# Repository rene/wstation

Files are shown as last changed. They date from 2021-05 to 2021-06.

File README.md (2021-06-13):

WStation Logo

*WStation* is a project that was born from my quarantine. I use to have one of those cheap Chinese thermometers. Unfortunately, it fell down to the floor, ending up with a broken LCD and a useless 433.92MHz sensor (since I didn't have any other device capable of decoding the signals). As you can imagine, perfect setup for a ESP32 project!

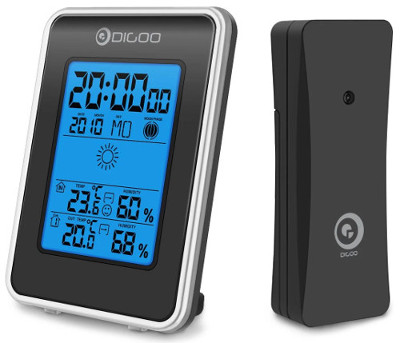
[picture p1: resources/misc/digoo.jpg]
Chinese Digoo Thermometer


*Original Device (Chinese Digoo thermometer)*

Since I had some free time due to the covid's quarantine, I've decided to start this project completely from scratch and release everything under BSD-3-Clause and CC licenses. Even the original mockup for the GUI can be found here.

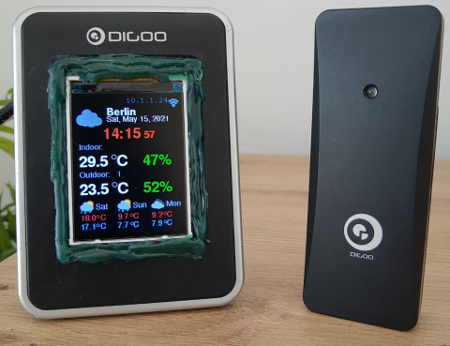
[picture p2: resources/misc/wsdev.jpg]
WStation device


*WStation device*

The prototype was made with a ESP32 DEVKIT V1 compatible device using the case of the broken Digoo thermometer (for sure there is room for visual improvements, specially on the hot glue the I've used to fill the holes on the borders, but in general the final result is not that bad). The radio receiver module have fit inside the case. ESP32 and DHT modules were assembled outside, on the back.

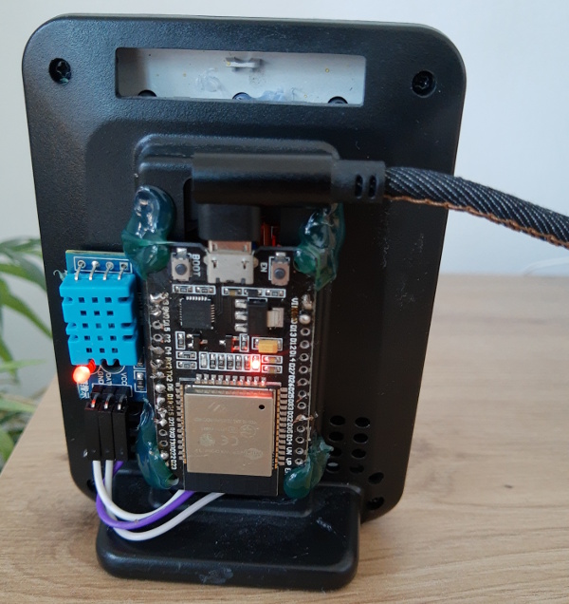
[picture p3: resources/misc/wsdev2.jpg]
WStation device - back


*ESP32 and DHT modules assembled on the back of the case*

WStation has the following features:

* WiFi connectivity
* NTP Client
* Timezone and Daylight Saving Time support
* Shows Indoor Temperature/Humidity
* Shows Outdoor (from external sensors) Temperature/Humidity (supports up to 3 sensors)
* Shows weekly forecast (next 3 days)
* Support to [OpenWeather](https://openweathermap.org/) API
* Support to DHT modules
* Support to HTU2x sensors
* Support to DS1307 RTC modules (optional)
* Support to 433.92MHz NC-7345 compatible sensors (optional)
* Web interface for device configuration (with user authentication)
* Reset setting to factory from button "press and hold"
* OTA firmware update (from Web interface)
* LCD brightness level control

## Hardware

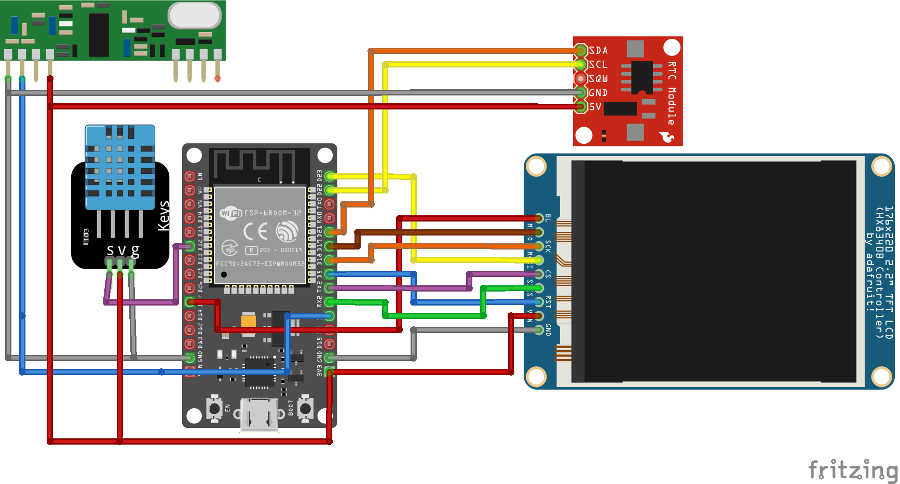
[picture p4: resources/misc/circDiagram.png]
WStation Circuit Diagram


*WStation circuit diagram*

The whole circuit can be built using a few modules:

| Module | Description |
| --- | --- |
| EPS32 module | ESP32 DEVKIT V1 compatible device |
| 240x320, 2.2" TFT LCD | SPI TFT LCD Serial Port Module Display ILI9341 5v/3.3v compatible screen |
| DHT module| DHT Sensor to measure Temperature and Humidity |
| DS1307 RTC module | Real Time Clock module (optional, date/time can be synchronized through NTP client) |
| 433.92MHz RF Receiver module | 433.92MHz RF Receiver (with ASK/OOK modulation support) |

DHT module can also be replaced by a high precision HTU2x Temperature/Humidity sensor module (connected through I2C):

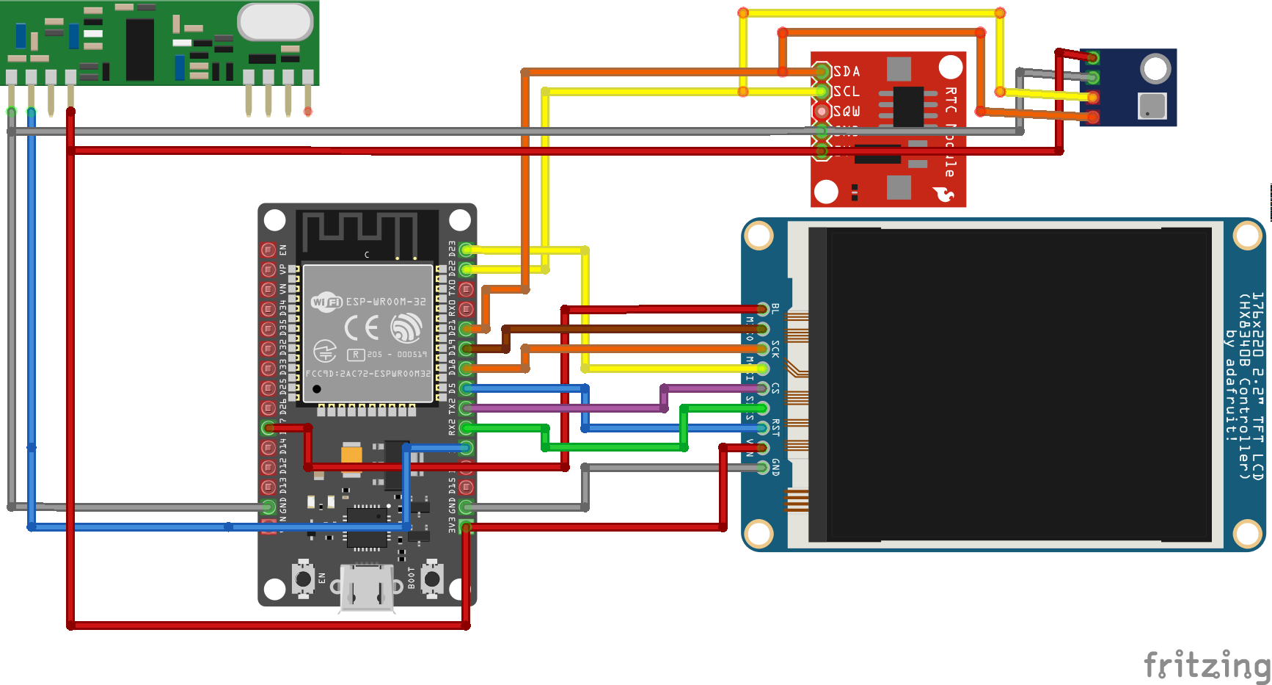
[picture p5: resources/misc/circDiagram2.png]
WStation Circuit Diagram with HTU2x sensor


### Pinout connection

| Function | Pin number |
| --- | --- |
| TFT module DC pin | 16 |
| TFT module CS pin| 17 |
| TFT module LED pin | 27 |
| TFT module SCK pin | 18 |
| TFT module MISO pin | 19 |
| TFT module MOSI pin | 23 |
| TFT module RST pin | 5 |
| DHT Data pin | 32 |
| Radio sensor | 4 |
| RTC SDA pin | 21 |
| RTC SCL pin | 22 |
| HTU2x SDA pin | 21 |
| HTU2x SCL pin | 22 |

## Firmware

### Setup the environment

To build the firmware, first make sure you have the Arduino/ESP32 environment installed as described at: [https://github.com/esp8266/Arduino](https://github.com/esp8266/Arduino) and [https://github.com/espressif/arduino-esp32](https://github.com/espressif/arduino-esp32). The firmware is built using *make* with the nice [makeEspArduino](https://github.com/plerup/makeEspArduino) makefile.

First, clone *WStation* repository:

```sh
git clone http://github.com/rene/wstation
cd wstation
```

Build and flash the file system:

```sh
$ cd src
$ make flash_fs
```

Build and flash the firmware:

```sh
$ make
$ make flash
```

Some environment variables can be customized according to user's setup:

| Variable | Description |
| --- | --- |
| UPLOAD_PORT | ESP module serial device, e.g. /dev/ttyUSB0 |
| UPLOAD_SPEED | Serial baud rate, e.g. 921600 |
| DEBUG_LEVEL | Verbose level for debug messages |
| RTC_DS1307 | Set to *true* if a RTC DS1307 module is installed |
| DHT_SENSOR | Set to *true* if a DHT module is installed |
| HTU2X_SENSOR | Set to *true* if a HTU2x modle is installed |
| ESP_LIBS | Path to Arduino/ESP libraries (if non default path is used) |
| ESP_ROOT | Root folder of Arduino/ESP environment (if non default path is used)  |

Once the device is flashed, future updates can be done through Web Interface. Just select and upload the *main.bin* file under *build* folder.

## Device setup

### Getting a OpenWeather API Key

*WStation* uses the [OpenWeather](https://openweathermap.org/) API to fetch updated weather forecasts. In order to use the API, you should subscribe to OpenWeather (free plan allows 60 requests per minute, which is completely fine for one *WStation* device) and get an API key. To get the key, please, follow the [Instructions](https://openweathermap.org/appid) at [OpenWeather](https://openweathermap.org/) website. After subscribe, you can generate and/or see your keys at the user's area:

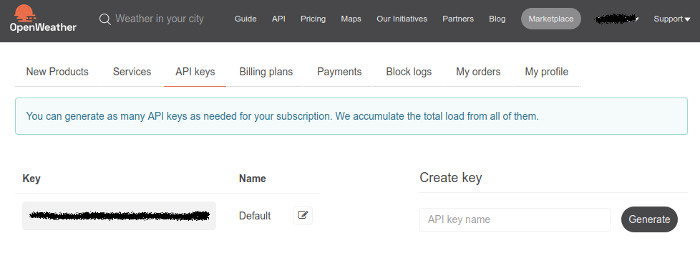
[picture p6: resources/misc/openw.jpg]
OpenWeather user interface


You will need to configure your API Key and city name (in OpenWeather's format, e.g. *Berlin,DE*) on *WStation* to start to get weather forecasts.

### Powering on the device

When you power on your *WStation* device for the first time, the device will act as an Access Point, creating the WiFi Network *WStation*. Connect to this network using the parameters shown on the screen:

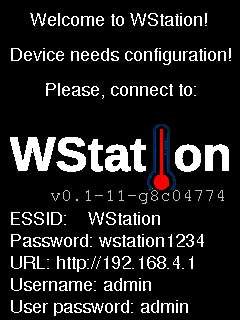
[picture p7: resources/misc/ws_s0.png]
WStation first screen


| Setting | Default value |
| --- | --- |
| WiFi SSID | *WStation* |
| WiFi Password | *wstation1234* |
| Username | *admin* |
| Password | *admin* |

Access device web interface to configure your API Key, City, WiFi network, etc. When the setup is done, click on the button *Save configuration*. That's it! Your *WStation* device is ready to work!

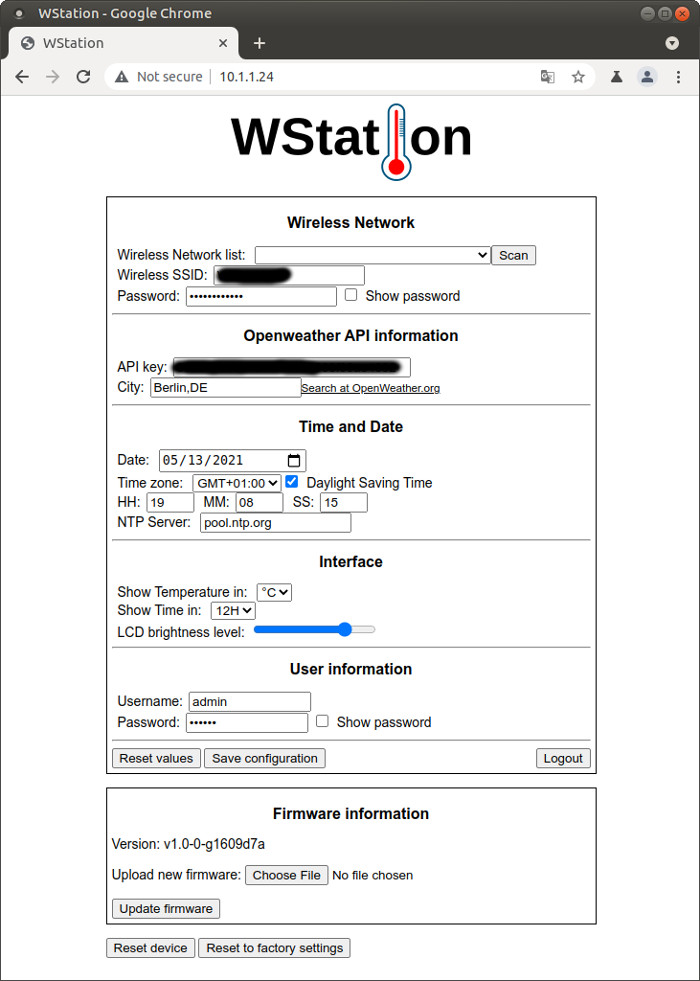
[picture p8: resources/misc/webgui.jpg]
WStation Web Interface


### Resseting to factory settings

Any *WStation* device can be redefined to factory settings by pressing and holding the *BOOT* button for 6 seconds or through the web interface.

### Screenshots of WStation interface

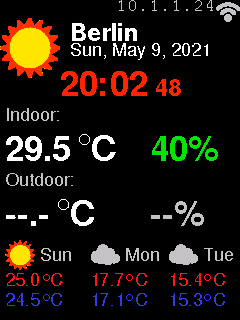
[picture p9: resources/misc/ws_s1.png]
WStation screenshot 1
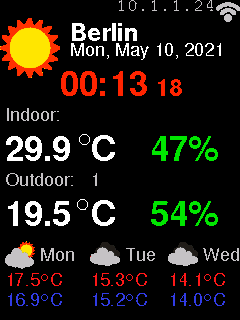
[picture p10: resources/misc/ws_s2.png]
WStation screenshot 2
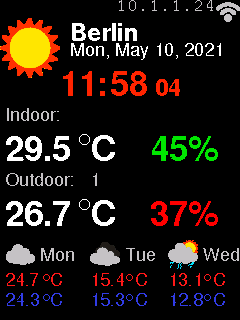
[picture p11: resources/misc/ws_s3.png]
WStation screenshot 3
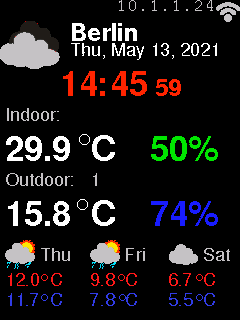
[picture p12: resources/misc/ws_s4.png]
WStation screenshot 4
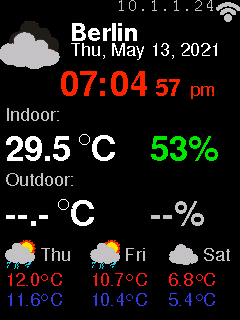
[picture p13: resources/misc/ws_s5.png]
WStation screenshot 5
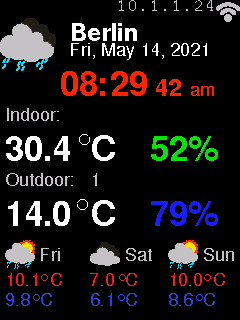
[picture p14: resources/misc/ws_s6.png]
WStation screenshot 6
     

## Bug reports

Please, report them on the project's GitHub page

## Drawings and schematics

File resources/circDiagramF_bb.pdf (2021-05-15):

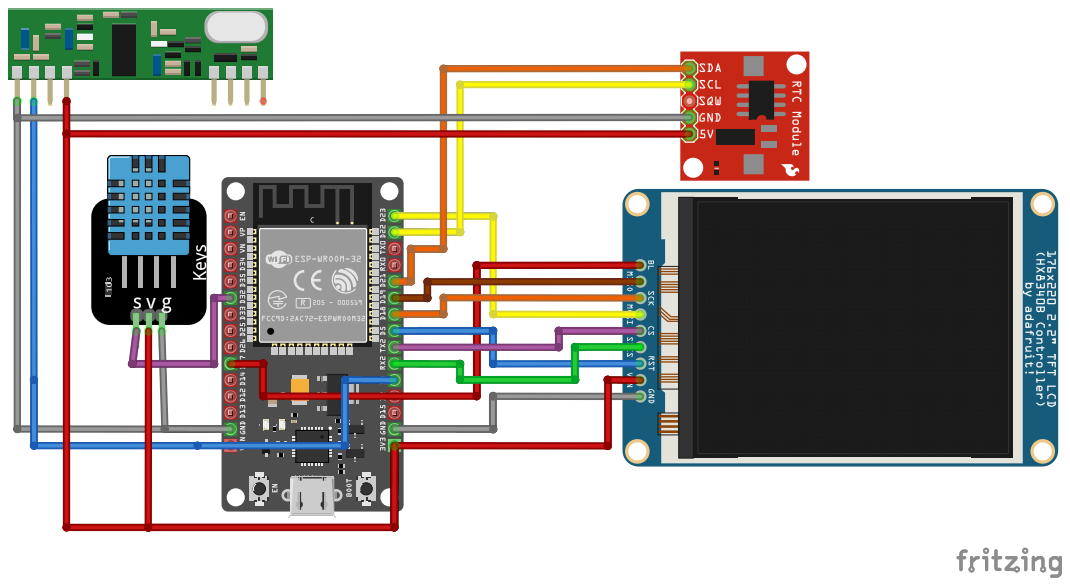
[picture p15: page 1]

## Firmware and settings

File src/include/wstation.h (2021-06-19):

/* SPDX-License-Identifier: BSD-3-Clause */
/* 
 * Copyright (c) 2020 Renê de Souza Pinto. All rights reserverd.
 *
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
 * Neither the name of the copyright holder nor the names of its contributors
 * may be used to endorse or promote products derived from this software without
 * specific prior written permission.
 *
 * THIS SOFTWARE IS PROVIDED BY THE COPYRIGHT HOLDERS AND CONTRIBUTORS "AS IS"
 * AND ANY EXPRESS OR IMPLIED WARRANTIES, INCLUDING, BUT NOT LIMITED TO, THE
 * IMPLIED WARRANTIES OF MERCHANTABILITY AND FITNESS FOR A PARTICULAR PURPOSE
 * ARE DISCLAIMED. IN NO EVENT SHALL THE COPYRIGHT HOLDER OR CONTRIBUTORS BE
 * LIABLE FOR ANY DIRECT, INDIRECT, INCIDENTAL, SPECIAL, EXEMPLARY, OR
 * CONSEQUENTIAL DAMAGES (INCLUDING, BUT NOT LIMITED TO, PROCUREMENT OF
 * SUBSTITUTE GOODS OR SERVICES; LOSS OF USE, DATA, OR PROFITS; OR BUSINESS
 * INTERRUPTION) HOWEVER CAUSED AND ON ANY THEORY OF LIABILITY, WHETHER IN
 * CONTRACT, STRICT LIABILITY, OR TORT (INCLUDING NEGLIGENCE OR OTHERWISE)
 * ARISING IN ANY WAY OUT OF THE USE OF THIS SOFTWARE, EVEN IF ADVISED OF THE
 * POSSIBILITY OF SUCH DAMAGE.
 */
/**
 * @file wstation.h
 * Custom types, defines and general configuration
 */
#ifndef __WSTATION_H__
#define __WSTATION_H__

#include <TimeLib.h>

/** Firmware version */
#ifndef WSTATION_VERSION
#define WSTATION_VERSION "0.1-static"
#endif

/** Web server port */
#define WEBSERVER_PORT 80

/** Time to retry network connection (in seconds) */
#define NETWORK_CONN_RETRY 20

/** Default WiFi SSID for AP mode */
#define DEFAULT_AP_SSID "WStation"
/** Default WiFi password for AP mode */
#define DEFAULT_AP_PASS "wstation1234"
/** Default username */
#define DEFAULT_USERNAME "admin"
/** Default user password */
#define DEFAULT_USER_PASS "admin"

/** LED pin */
#define LED_PIN 2

/** User reset button (BOOT button) */
#define USER_RESET_BUTTON 0
/** Reset button pressing time for factory reset */
#define USER_RESET_PTIME 6

/** 433MHz module receiver Data pin */
#define RF_PIN  4

/** DHT sensor data pin */
#define DHT_DATA_PIN 32

/** TFT module DC pin */
#define TFT_DC 16
/** TFT module CS pin */
#define TFT_CS 17
/** TFT module led pin */
#define TFT_BACKLIGHT 27

/** Sensor data display interval (in seconds) */
#define SENSOR_DISPLAY_INTERVAL 5

/** Sensor data expiration period (in seconds) */
#define SENSOR_DATA_EXPIRATION 600

/** Weather information update interval (in seconds) */
#define WEATHER_UPDATE_INTERVAL 60

/** NTP date/time update interval (in seconds) */
#define NTP_UPDATE_INTERVAL 1800

/** Humidity level: Low (dry) */
#define HUMIDITY_L0_LOW    0
/** Humidity level: Comfortable */
#define HUMIDITY_L1_IDEAL 40
/** Humidity level: High */
#define HUMIDITY_L2_HIGH  70

/** Types of pixmaps in the LCD screen */
typedef enum _weather_id {
	/** Unknown */
	UNKNOWN_WEATHER = 0,
	/** Thunderstorm: Light rain */
	THUNDERSTORM_LIGHT_RAIN = 200,
	/** Thunderstorm: Rain */
	THUNDERSTORM_RAIN = 201,
	/** Thunderstorm: Heavy rain */
	THUNDERSTORM_HEAVY_RAIN = 202,
	/** Thunderstorm: Light */
	THUNDERSTORM_LIGHT = 210,
	/** Thunderstorm */
	THUNDERSTORM = 211,
	/** Thunderstorm: Heavy */
	THUNDERSTORM_HEAVY = 212,
	/** Thunderstorm: Ragged */
	THUNDERSTORM_RAGGED = 221,
	/** Thunderstorm: Light drizzle */
	THUNDERSTORM_LIGHT_DRIZZLE = 230,
	/** Thunderstorm: drizzle */
	THUNDERSTORM_DRIZZLE = 231,
	/** Thunderstorm: Heavy drizzle */
	THUNDERSTORM_HEAVY_DRIZZLE = 232,
	/** Drizzle: Light */
	DRIZZLE_LIGHT = 300,
	/** Drizzle */
	DRIZZLE = 301,
	/** Drizzle: Heavy */
	DRIZZLE_HEAVY = 302,
	/** Drizzle: Light drizzle rain */
	DRIZZLE_LIGHT_RAIN = 310,
	/** Drizzle: Rain */
	DRIZZLE_RAIN = 311,
	/** Drizzle: Heavy drizzle rain */
	DRIZZLE_HEAVY_RAIN = 312,
	/** Drizzle: Shower rain */
	DRIZZLE_SHOWER_RAIN = 313,
	/** Drizzle: Heavy shower rain and drizzle */
	DRIZZLE_HEAVY_SHOWER_RAIN = 314,
	/** Drizzle: Shower */
	DRIZZLE_SHOWER = 321,
	/** Rain: Light */
	RAIN_LIGHT = 500,
	/** Rain: Moderate */
	RAIN_MODERATE = 501,
	/** Rain: Heavy */
	RAIN_HEAVY = 502,
	/** Rain: Very heavy */
	RAIN_VERY_HEAVY = 503,
	/** Rain: Extreme */
	RAIN_EXTREME = 504,
	/** Rain: Freezing */
	RAIN_FREEZING = 511,
	/** Rain: Light shower */
	RAIN_LIGHT_SHOWER = 520,
	/** Rain: Shower */
	RAIN_SHOWER = 521,
	/** Rain: Heavy shower */
	RAIN_HEAVY_SHOWER = 522,
	/** Rain: Ragged */
	RAIN_RAGGED = 531,
	/** Snow: Light */
	SNOW_LIGHT = 600,
	/** Snow */
	SNOW = 601,
	/** Snow: Heavy */
	SNOW_HEAVY = 602,
	/** Snow: Sleet */
	SNOW_SLEET = 611,
	/** Snow: Light shower sleet */
	SNOW_LSHOWER_SLEET = 612,
	/** Snow: Shower sleet */
	SNOW_SHOWER_SLEET = 613,
	/** Snow: XX */
	SNOW_LIGHT_RAIN = 615,
	/** Snow: XX */
	SNOW_RAIN = 616,
	/** Snow: Light shower */
	SNOW_LIGHT_SHOWER = 620,
	/** Snow: Shower */
	SNOW_SHOWER = 621,
	/** Snow: Heavy shower */
	SNOW_HEAVY_SHOWER = 622,
	/** Atmosphere: Mist */
	ATM_MIST = 701,
	/** Atmosphere: Smoke */
	ATM_SMOKE = 711,
	/** Atmosphere: Haze */
	ATM_HAZE = 721,
	/** Atmosphere: Dust whirls */
	ATM_DUST_WHIRLS = 731,
	/** Atmosphere: Fog */
	ATM_FOG = 741,
	/** Atmosphere: Sand */
	ATM_SAND = 751,
	/** Atmosphere: Dust */
	ATM_DUST = 761,
	/** Atmosphere: Volcanic ash */
	ATM_VOLCANIC_ASH = 762,
	/** Atmosphere: Squalls */
	ATM_SQUALL = 771,
	/** Atmosphere: XX */
	ATM_TORNADO = 781,
	/** Clear */
	CLEAR_SKY = 800,
	/** Clouds: Few */
	CLOUDS_FEW = 801,
	/** Clouds: Scattered */
	CLOUDS_SCATTERED = 802,
	/** Clouds: Broken */
	CLOUDS_BROKEN = 803,
	/** Clouds: Overcast */
	CLOUDS_OVERCAST = 804,
} weather_t;

/** Temperature scale */
typedef enum _temp_scale {
	/** Celsius */
	CELSIUS = 0,
	/** Fahrenheit */
	FAHRENHEIT,
} temp_scale_t;

/** Time format */
typedef enum _time_format {
	/** 24 Hours */
	TIME_FORMAT_24H = 0,
	/** 12 Hours */
	TIME_FORMAT_12H,
} time_format_t;

/** Wall clock */
extern tmElements_t wallClock;

/* Prototypes */

void userSetupDone(void);
void WiFiReconnect(void);
void updateFromConf(void);
void factoryReset(void);
#ifdef DEBUG_SCREENSHOT
void takeScreenshot(void);
#endif
#endif /* __WSTATION_H__ */

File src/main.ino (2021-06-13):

/* SPDX-License-Identifier: BSD-3-Clause */
/*
 * Copyright 2020 Renê de Souza Pinto
 *
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
 * Neither the name of the copyright holder nor the names of its contributors
 * may be used to endorse or promote products derived from this software without
 * specific prior written permission.
 *
 * THIS SOFTWARE IS PROVIDED BY THE COPYRIGHT HOLDERS AND CONTRIBUTORS "AS IS"
 * AND ANY EXPRESS OR IMPLIED WARRANTIES, INCLUDING, BUT NOT LIMITED TO, THE
 * IMPLIED WARRANTIES OF MERCHANTABILITY AND FITNESS FOR A PARTICULAR PURPOSE
 * ARE DISCLAIMED. IN NO EVENT SHALL THE COPYRIGHT HOLDER OR CONTRIBUTORS BE
 * LIABLE FOR ANY DIRECT, INDIRECT, INCIDENTAL, SPECIAL, EXEMPLARY, OR
 * CONSEQUENTIAL DAMAGES (INCLUDING, BUT NOT LIMITED TO, PROCUREMENT OF
 * SUBSTITUTE GOODS OR SERVICES; LOSS OF USE, DATA, OR PROFITS; OR BUSINESS
 * INTERRUPTION) HOWEVER CAUSED AND ON ANY THEORY OF LIABILITY, WHETHER IN
 * CONTRACT, STRICT LIABILITY, OR TORT (INCLUDING NEGLIGENCE OR OTHERWISE)
 * ARISING IN ANY WAY OUT OF THE USE OF THIS SOFTWARE, EVEN IF ADVISED OF THE
 * POSSIBILITY OF SUCH DAMAGE.
 */
/**
 * @file main.ino
 * Main tasks, setup(), loop() and auxiliary functions
 */
#include <WiFi.h>
#include <esp_wifi.h>
#include <SPI.h>
#include <FS.h>
#include <SPIFFS.h>
#include <TimeLib.h>
#include <AsyncTCP.h>
#include <ESPAsyncWebServer.h>
#include <ArduinoNvs.h>
#include "wstation.h"
#include "clock.h"
#include "nexus.h"
#include "ETheme.h"
#include "EInterface.h"
#include "OpenWeather.h"
#include "UserConf.h"
#include "webservices.cpp"

/** User configuration data */
UserConf confData;
/** Embedded GUI */
EInterface *gui = NULL;
/** Color theme */
ETheme colorTheme;
/** OpenWeather */
OpenWeather weatherWS;
/** Wall clock */
tmElements_t wallClock;
/** Web server */
AsyncWebServer webServer(WEBSERVER_PORT);

#ifdef DHT_SENSOR
#include <DHSensor.h>
/** DHT sensor */
DHTSensor tempHSensor;
#elif HTU2X_SENSOR
#include <HTU2XSensor.h>
HTU2XSensor tempHSensor;
#else
#error You should enable at least one Temperature/Humidity sensor
#endif

/** Mutex for screen update */
volatile SemaphoreHandle_t t_mutex;

/** Mutex for wall clock update */
volatile SemaphoreHandle_t clk_mutex;

/** Mutex for restart device */
volatile SemaphoreHandle_t reset_mutex;

/** Wait for user initial setup */
volatile SemaphoreHandle_t setup_sem;

/** WiFi reset */
volatile SemaphoreHandle_t wifi_mutex;

/** Last weather information update */
unsigned long lastUpdate;

/** Last NTP date/time update */
unsigned long lastNTPUpdate;

/** Update the date on main screen */
bool updateStrDate;


/**
 * Format city string
 * @param [in] city City
 * @return String
 */
String formatCity(const String& city)
{
	int cpos = city.indexOf(",");
	if (cpos > 0) {
		return city.substring(0, cpos);
	} else {
		return city;
	}
}

/**
 * Format date into string
 * @param [in] tm Time
 * @return String
 */
String formatDate(tmElements_t tm)
{
	String dateStr;
	dateStr = String(dayStr(tm.Wday)).substring(0,3) + ", "
				+ String(monthStr(tm.Month)).substring(0,3) + " "
				+ String(tm.Day) + ", "
				+ String(tmYearToCalendar(tm.Year));
	return dateStr;
}

/**
 * Format IP address into string
 * @param [in] ipAddr IP Address
 * @return String
 */
String formatIP(IPAddress ipAddr)
{
	char ip[40];
	snprintf(ip, 40, "%d.%d.%d.%d", ipAddr[0], ipAddr[1], ipAddr[2], ipAddr[3]);
	return String(ip);
}

/**
 * Indicates that user setup is done
 */
void userSetupDone(void)
{
	xSemaphoreGive(setup_sem);
}

/**
 * Perform WiFi reconnection
 */
void WiFiReconnect(void)
{
	xSemaphoreTake(wifi_mutex, portMAX_DELAY);
	log_i("Resetting WiFi connection...");
	WiFi.disconnect();
	delay(1000);
	WiFi.mode(WIFI_STA);
	WiFi.begin(confData.getWiFiSSID().c_str(),
				confData.getWiFiPassword().c_str());
	xSemaphoreGive(wifi_mutex);
}

/**
 * Update screen elements from user configuration
 */
void updateFromConf(void)
{
	int d, m, y, w;
	wifi_config_t conf;

	// Get WiFi configuration
	esp_wifi_get_config(WIFI_IF_STA, &conf);
	String wifi_ssid = String(reinterpret_cast<const char*>(conf.sta.ssid));
	String wifi_pass = String(reinterpret_cast<const char*>(conf.sta.password));

	// Check if WiFi network configuration have changed
	if (wifi_ssid != confData.getWiFiSSID() ||
		wifi_pass != confData.getWiFiPassword())
		WiFiReconnect();

	// Update calendar, daylight and timezone values are used only for NTP
	// server (in order to perform the right time shift)
	xSemaphoreTake(clk_mutex, portMAX_DELAY);
	confData.getDate(&d, &m, &y, &w);

	wallClock.Day    = d;
	wallClock.Month  = m;
	wallClock.Year   = CalendarYrToTm(y);

	wallClock.Hour   = confData.getHours();
	wallClock.Minute = confData.getMinutes();
	wallClock.Second = confData.getSeconds();
	writeClock(&wallClock);
	xSemaphoreGive(clk_mutex);

	xSemaphoreTake(t_mutex, portMAX_DELAY);
	// LCD backlight
	gui->setBacklight(confData.getLCDBrightness());
	// Temperature scale
	gui->setTempScale(confData.getTempScale());
	// Time format
	gui->setTimeFormat(confData.getTimeFormat());
	xSemaphoreGive(t_mutex);

	// Set to update date string
	xSemaphoreTake(t_mutex, portMAX_DELAY);
	updateStrDate = true;
	xSemaphoreGive(t_mutex);
}

/**
 * Perform factory reset
 */
void factoryReset(void)
{
	// Acquire mutex to reset device, we should never return from here
	xSemaphoreTake(reset_mutex, portMAX_DELAY);
	// Reset settings
	confData.ResetConf();
	// Restart system
	esp_restart();
	// Should never reach here: do not release the mutex for safety reasons
}

#ifdef DEBUG_SCREENSHOT
/**
 * Take a screenshot of the screen (for debug purposes)
 */
void takeScreenshot(void)
{
	digitalWrite(LED_PIN, HIGH);
	xSemaphoreTake(t_mutex, portMAX_DELAY);
	gui->takeScreenshot("/screenshot.px");
	delay(100);
	xSemaphoreGive(t_mutex);
	digitalWrite(LED_PIN, LOW);
}
#endif

/**
 * Update graphical elements on the screen
 * @param parameter Task parameters (not used)
 */
void taskUpdateScreen(void *parameter)
{
	int ret;
	updateStrDate = true;
	while(1) {
		// Update clock
		xSemaphoreTake(clk_mutex, portMAX_DELAY);
		ret = readClock(&wallClock);
		xSemaphoreGive(clk_mutex);
		if (ret < 0) {
			log_e("Read clock error!");
			xSemaphoreTake(clk_mutex, portMAX_DELAY);
			wallClock.Day    = 1;
			wallClock.Month  = 1;
			wallClock.Year   = CalendarYrToTm(2020);
			wallClock.Hour   = 0;
			wallClock.Minute = 0;
			wallClock.Second = 0;
			writeClock(&wallClock);
			xSemaphoreGive(clk_mutex);

			updateStrDate = true;
		} else {
			if (wallClock.Hour == 0 && wallClock.Minute == 0) {
				updateStrDate = true;
			}

			xSemaphoreTake(t_mutex, portMAX_DELAY);
			if (gui) {
				gui->setHours(wallClock.Hour);
				gui->setMinutes(wallClock.Minute);
				gui->setSeconds(wallClock.Second);
				if (updateStrDate) {
					gui->setDate(formatDate(wallClock));
					updateStrDate = false;
				}
			}
			xSemaphoreGive(t_mutex);
		}
		delay(1000);
	}
}

/**
 * Update forecast information on the screen
 * @param parameter Task parameters (not used)
 */
void taskUpdateWeatherInfo(void *parameter)
{
	int i;
	float t1, tf1, tf2;
	weather_info_t wfc;

	while (1) {
		if (WiFi.status() == WL_CONNECTED) {
			if ((now() - lastUpdate) >= WEATHER_UPDATE_INTERVAL) {
				lastUpdate = now();

				if (weatherWS.updateForecast() != 0) {
					log_e("Error to retrieve forecast!");
				} else {
					weather_info_t w = weatherWS.getDailyForecast();
					t1 = OpenWeather::convKelvinTemp(w.temp, CELSIUS);

					xSemaphoreTake(t_mutex, portMAX_DELAY);
					gui->showWeather(w.weather, 0);

					for (i = 0; i < 3; i++) {
						wfc = weatherWS.getWeeklyForecast(i);
						tf1 = OpenWeather::convKelvinTemp(wfc.feels, CELSIUS);
						tf2 = OpenWeather::convKelvinTemp(wfc.temp, CELSIUS);

						gui->showForecastLabel(i, dayShortStr(weekday(wfc.date)));
						gui->showForecastTemp1(i, tf1);
						gui->showForecastTemp2(i, tf2);
						gui->showForecastWeather(i, wfc.weather);
					}
					xSemaphoreGive(t_mutex);
				}
			}
		}
		delay(1000);
	}
}

/**
 * Update NTP date/time information
 * @param parameter Task parameters (not used)
 */
void taskUpdateNTP(void *parameter)
{
	int i;
	float t1, tf1, tf2;
	weather_info_t wfc;

	while (1) {
		if (WiFi.status() == WL_CONNECTED) {
			if ((now() - lastNTPUpdate) >= NTP_UPDATE_INTERVAL) {
				lastNTPUpdate = now();

				// NTP update
				xSemaphoreTake(clk_mutex, portMAX_DELAY);
				configTime(confData.getTimezone(), confData.getDaylight(),
					confData.getNTPServer().c_str());
				// Update wall clock
				getSysClock(&wallClock);
				xSemaphoreGive(clk_mutex);

				// Update date on screen (time will be updated on the next
				// second)
				xSemaphoreTake(t_mutex, portMAX_DELAY);
				updateStrDate = true;
				xSemaphoreGive(t_mutex);
			}
		}
		delay(1000);
	}
}

/**
 * Read Temperature and Humidity sensor data
 * @param parameter Task parameters (not used)
 */
void taskReadTHSensor(void *parameter)
{
	while (1) {
		tempHSensor.readSensor();

		if (tempHSensor.getStatus() != 0) {
			log_e("Temp./Hum. sensor error status: %s",
					tempHSensor.getStatusString());
		} else {
			// Display data
			xSemaphoreTake(t_mutex, portMAX_DELAY);
			gui->showTemp1(tempHSensor.getTemperature());
			gui->showHumidity1(tempHSensor.getHumidity());
			xSemaphoreGive(t_mutex);
		}

		delay(10000);
	}
}

/**
 * Receive nexus sensor data
 * @param parameter Task parameters (not used)
 */
void taskReceiveSensorData(void *parameter)
{
	int i, ch, disp;
	nexus_t sensors[3];
	unsigned long lastShow, lastData[3];
	float t;

	// Invalidate initial data
	for (i = 0; i < 3; i++) {
		sensors[i].flags.fields.channel = NEXUS_INVALID_CHANNEL;
	}

	i        = 0;
	disp     = 0;
	lastShow = now();
	while (1) {
		// Check if we have received data
		if (nexusDataAvailable) {
			portENTER_CRITICAL(&nexusMutex);

			nexusDataAvailable = false;

			// Read channel
			ch = nexusData.flags.fields.channel;
			if (ch >= NEXUS_CHANNEL_1 && ch <= NEXUS_CHANNEL_3) {
				i = ch;
			} else {
				// Invalid channel
				portEXIT_CRITICAL(&nexusMutex);
				continue;
			}

			// Copy data
			sensors[i].id          = nexusData.id;
			sensors[i].flags.raw   = nexusData.flags.raw;
			sensors[i].temperature = nexusData.temperature;
			sensors[i].humidity    = nexusData.humidity;
			lastData[i]            = now();

			// Check humidity value
			if (sensors[i].humidity > 100)
				sensors[i].humidity = 100;

			portEXIT_CRITICAL(&nexusMutex);

			// Indicate on screen that data has been received
			xSemaphoreTake(t_mutex, portMAX_DELAY);
			gui->showRadio(true);
			delay(300);
			gui->showRadio(false);
			xSemaphoreGive(t_mutex);
		}

		// Show data on the screen
		if ((now() - lastShow) >= SENSOR_DISPLAY_INTERVAL) {
			if (sensors[disp].flags.fields.channel != NEXUS_INVALID_CHANNEL) {
				// Check for how long sensor data has not been updated
				lastShow = now();
				if ((lastShow - lastData[disp]) <= SENSOR_DATA_EXPIRATION) {
					t = (float)sensors[disp].temperature / 10;
					xSemaphoreTake(t_mutex, portMAX_DELAY);
					gui->showChannel(sensors[disp].flags.fields.channel + 1);
					gui->showTemp2(t);
					gui->showHumidity2(sensors[disp].humidity);
					xSemaphoreGive(t_mutex);
				} else {
					// Sensor data is expired, let's invalidate it
					sensors[disp].flags.fields.channel = NEXUS_INVALID_CHANNEL;
					xSemaphoreTake(t_mutex, portMAX_DELAY);
					gui->showChannel(GUI_INV_CHANNEL);
					gui->showTemp2(GUI_INV_TEMP);
					gui->showHumidity2(GUI_INV_HUMIDITY);
					xSemaphoreGive(t_mutex);
				}
			}

			disp++;
			if (disp >= 3) {
				disp = 0;
			}
		}

		delay(1000);
	}
}

/**
 * Setup
 */
void setup() {
	// Initialize serial
	Serial.begin(115200);
	Serial.print("WSTATION: ");
	Serial.println(WSTATION_VERSION);

	// Initialize general purpose LED
	pinMode(LED_PIN, OUTPUT);
	digitalWrite(LED_PIN, LOW);

	// Initialize BOOT button
	pinMode(USER_RESET_BUTTON, INPUT);

	// Initialize SPIFFS file system
	if(!SPIFFS.begin(false)){
		log_e("SPIFFS Mount Failed");
		log_e("Abort.");
		return;
    }

	// Initialize NVS
	NVS.begin();

	delay(500);

	// Initialize semaphores
	vSemaphoreCreateBinary(t_mutex);
	vSemaphoreCreateBinary(clk_mutex);
	vSemaphoreCreateBinary(reset_mutex);
	vSemaphoreCreateBinary(wifi_mutex);
	setup_sem = xSemaphoreCreateCounting(1, 0);

	// Initialize embedded GUI
	gui = new EInterface(TFT_CS, TFT_DC,
			TFT_BACKLIGHT, BACKLIGHT_DEFAULT, colorTheme,
			&SPIFFS);

	gui->initialize();
	gui->showLogo();
	gui->showVersion(50, 200);
	delay(700);

	// Initialize Temperature/Humidity sensor
	tempHSensor.setup();

	// Initialize 433MHz module receiver
	setupNexus(RF_PIN);

	// Read user configuration
	confData.ReadConf();

	// Configure web server
	SetupWebServices(&webServer);

	// Check for valid configuration
	if (!confData.isConfigured()) {
		// Reset conf
		confData.ResetConf();

		// Create Access Point
		WiFi.softAP(DEFAULT_AP_SSID, DEFAULT_AP_PASS);
		String ip("  URL: http://");
		ip.concat(formatIP(WiFi.softAPIP()));
		ip.concat("\n");

		// Start web server
		webServer.begin();

		// Show instructions on screen
		xSemaphoreTake(t_mutex, portMAX_DELAY);
		gui->print(30, 25, "Welcome to WStation!");
		gui->print(10, 60, "Device needs configuration!");
		gui->print(45, 95, "Please, connect to:");
		gui->print(0, 224, "  ESSID:    " DEFAULT_AP_SSID "\n");
		gui->print("  Password: " DEFAULT_AP_PASS "\n");
		gui->print(ip);
		gui->print("  Username: " DEFAULT_USERNAME "\n");
		gui->print("  User password: " DEFAULT_USER_PASS "\n");
		xSemaphoreGive(t_mutex);

		// Wait until setup is done
		xSemaphoreTake(setup_sem, portMAX_DELAY);
	}

	// Device is configured, proceed with initialization
	lastUpdate    = now() - WEATHER_UPDATE_INTERVAL;
	lastNTPUpdate = now() - NTP_UPDATE_INTERVAL + 5;

	WiFi.mode(WIFI_STA);
	WiFi.begin(confData.getWiFiSSID().c_str(),
				confData.getWiFiPassword().c_str());
	weatherWS.setAPIKey(confData.getAPIKey());
	weatherWS.setCity(confData.getCity());

	gui->clearAll();
	gui->showAll();
	gui->setCity(formatCity(weatherWS.getCity()));

	updateFromConf();

	xTaskCreate(taskUpdateScreen,      "UpdateScreen",      16384, NULL, 2, NULL);
	xTaskCreate(taskReceiveSensorData, "ReceiveSensorData", 16384, NULL, 0, NULL);
	xTaskCreate(taskUpdateWeatherInfo, "UpdateWeatherInfo", 36864, NULL, 0, NULL);
	xTaskCreate(taskUpdateNTP,         "UpdateNTP",          8192, NULL, 0, NULL);
	xTaskCreate(taskReadTHSensor,      "ReadTHSensor",       4096, NULL, 0, NULL);
}

/**
 * Main loop
 */
void loop()
{
	int status     = WL_IDLE_STATUS;
	bool wsinit    = false;
	bool icon      = false;
	int nocontimer = 0;
	int resettimer = 0;
	int i;

	while (1) {
		// User reset button
		if (digitalRead(USER_RESET_BUTTON) == LOW) {
			// Debounce
			delay(50);
			if (digitalRead(USER_RESET_BUTTON) == LOW) {
				// Increment counter
				resettimer++;
				log_i("Reset button pressed: %d", resettimer);
				if (resettimer >= USER_RESET_PTIME) {
					log_i("Performing factory resetting...");
					factoryReset();
				}
			} else {
				resettimer = 0;
			}
		} else {
			resettimer = 0;
		}

		// WiFi status
		status = WiFi.status();

		switch(status) {
			case WL_IDLE_STATUS:
			case WL_NO_SSID_AVAIL:
				do {
					if (nocontimer < NETWORK_CONN_RETRY)
						nocontimer++;
					else
						break;

					status = WiFi.status();

					if (icon == false)
						icon = true;
					else
						icon = false;

					xSemaphoreTake(t_mutex, portMAX_DELAY);
					gui->showWiFi(icon);
					gui->setIP("");
					xSemaphoreGive(t_mutex);
					delay(1000);
				} while (status == WL_IDLE_STATUS ||
						 status == WL_NO_SSID_AVAIL);
				break;

			case WL_CONNECTED:
				xSemaphoreTake(t_mutex, portMAX_DELAY);
				gui->showWiFi(true);
				gui->setIP(formatIP(WiFi.localIP()));
				xSemaphoreGive(t_mutex);

				if (!wsinit) {
					wsinit = true;
					webServer.begin();
				}
				nocontimer = 0;
				break;

			case WL_SCAN_COMPLETED:
			case WL_NO_SHIELD:
			case WL_CONNECT_FAILED:
			case WL_CONNECTION_LOST:
			case WL_DISCONNECTED:
			default:
				xSemaphoreTake(t_mutex, portMAX_DELAY);
				gui->showWiFi(false);
				gui->setIP("");
				xSemaphoreGive(t_mutex);
				nocontimer++;
				break;
		}

		// Check for connection retry
		if (nocontimer >= NETWORK_CONN_RETRY) {
			// Try to reconnect
			WiFiReconnect();

			// Quick blink WiFi icon
			xSemaphoreTake(t_mutex, portMAX_DELAY);
			for (i = 0; i < 4; i++) {
				if ((i % 2) == 0)
					gui->showWiFi(true);
				else
					gui->showWiFi(false);
				delay(400);
			}
			xSemaphoreGive(t_mutex);

			// Reset timer counter
			nocontimer = 0;
		}

		delay(1000);
	}
}

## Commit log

2021-05-15 WStation: Initial Release
    WStation: Weather Station with ESP32
    * Version: 1.0
    [circDiagramF.fzz]
2021-06-13 makeEspArduino.mk: Fix pattern for bin file.
    Fix pattern in makeEspArduino.mk to conform with newer Arduino IDE.
2021-06-13 main.ino: Introduce abstract class for Temperature and Humidity sensors.
    - Introduce abstract class for Temperature and Humidity sensors
    - Add class implementation for DHT Sensors
2021-06-13 Add support to HTU2x Temperature/Humidity sensors.
    - Add support to HTU2x Temperature/Humidity high precision sensors
    - Add SparkFunHTU21D library
    - Add updated circuit diagram
    - Add documentation to README.md
    [circDiagramF2.fzz]
2021-06-19 nexus.cpp: Change input pin configuration
    Remove default PULLUP (reception improvement was noticed).
2021-06-29 nexus.cpp: Discard radio sensor buffer when invalid data is received
    - When radio signal are too much attenuated it might be difficult to receive
    three consecutive good frames. If a invalid frame is received, discard the whole
    buffer to get all frames from next transmission.
